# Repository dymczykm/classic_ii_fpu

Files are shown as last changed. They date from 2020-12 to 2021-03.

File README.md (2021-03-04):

# Macintosh Classic II FPU card

This repo contains a KiCAD design of an expansion card that adds an MC68882 FPU to your Macintosh Classic II. The board has two layers to keep the PCB cost down. It offers a switchable clock source between the system clock (16 MHz, synchronous operation) and a crystal oscillator on the board (40 MHz, asynchronous operation; tested with MC68882FN40A, the rumours claim 50 MHz will work too).

### Results

After plugging in the card, it should be immediately visible in some tools (here System Information of MacBench):
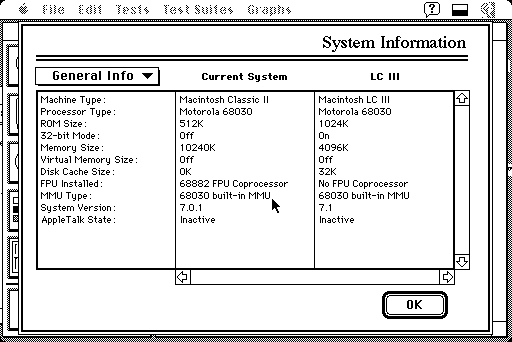
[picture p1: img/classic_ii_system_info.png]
FPU card present in System Information


The board dramatically improves the Floating Point performance of the computer. MacBench 1.0 with an FPU@16 MHz (system clock) reports over a 13x improvement.
When using an external 40 MHz oscillator, the Floating Point result goes up even a bit more - to 15.7x (it's not proportional to the clock frequency as at some point the slow 16-bit bus becomes a limiting factor):

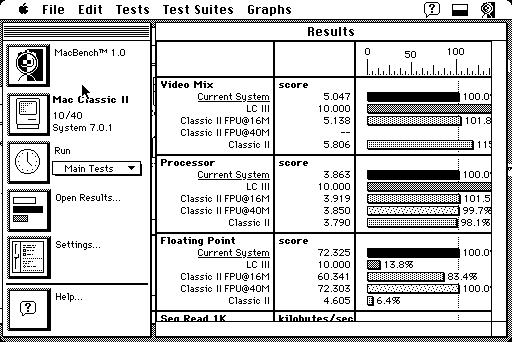
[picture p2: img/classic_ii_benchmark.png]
FPU benchmark showing Floating Point improvements


(look at the Floating Point row)

### Order a PCB

If you want to order a PCB directly, I have created a project on PCBWay:
https://www.pcbway.com/project/shareproject/Macintosh_Classic_II_FPU_card.html

### Bill of Materials

| Qty | Value | Device | Package | Parts | Digikey reference | 
|-----|---|---|---|---|---|
| 1 | | MC68882FN40A | PLCC68 | IC1 | | 
| 1 | | PLCC68 socket | PLCC68 | hosts IC1 | 2057-PLCC-68-AT-ND | 
| 1 | | TE 5-532955-8 | | J2 | A34313-ND | 
| 1 | | Pin Header 2.54mm  | 3 pins | J1 | |
| 6 | 100nF X7R | SMD capacitor | 0805 | C1-C5, C7 | 399-17169-6-ND | 
| 1 | 10uF 10V | Tantalum Cap | A (3216) | C6 | 399-4788-1-ND | 
| 1 | 51 ohm | SMD resistor | 0805 | R1 | A126374CT-ND | 
| 1 | 40 MHz | Crystal oscillator | DIP-8 | X1 | e.g. MXO45HS-2C-40M000000 | 
| 1 | | Shunt jumper | | over J1 | 881545-1 | 

(sorry, I had most components at hand, so I only have Digikey references for the rather specific ones)

### Pictures

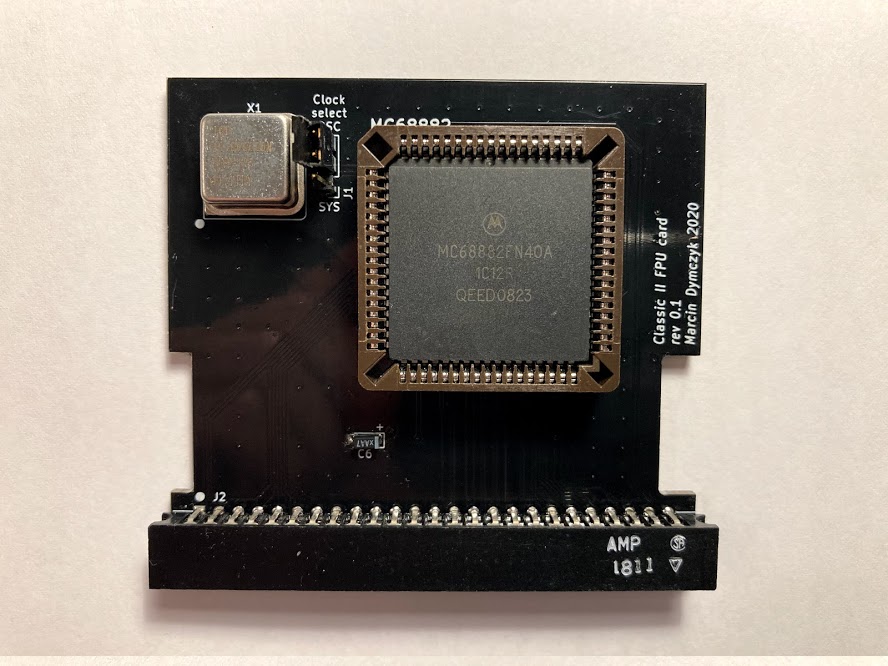
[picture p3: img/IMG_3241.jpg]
FPU top


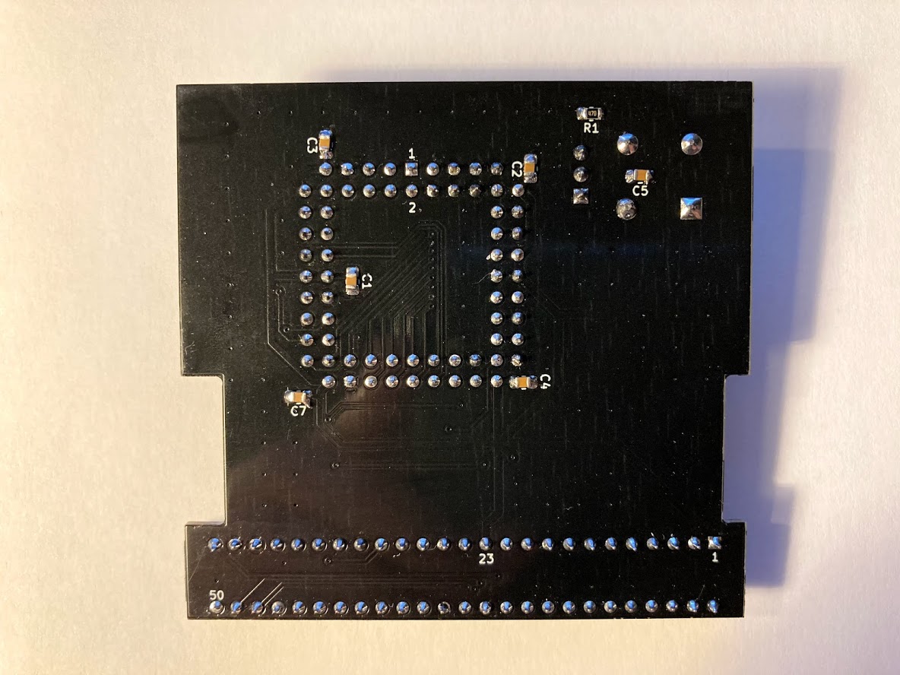
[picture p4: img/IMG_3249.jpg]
FPU bottom


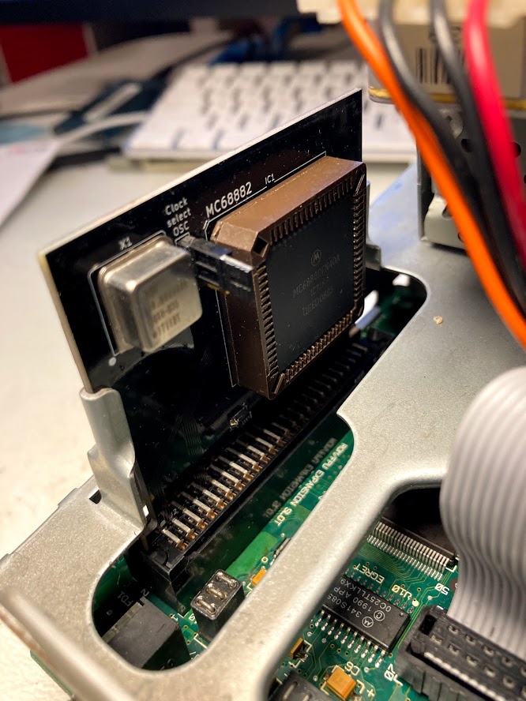
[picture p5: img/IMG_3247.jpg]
FPU installed


### References and Credits

The MC68000 KiCAD library from https://dev.sigpipe.me/DashieElectronics/Jackalope

Thanks to [pfuentes69](https://github.com/pfuentes69) for providing the missing Digikey PNs.

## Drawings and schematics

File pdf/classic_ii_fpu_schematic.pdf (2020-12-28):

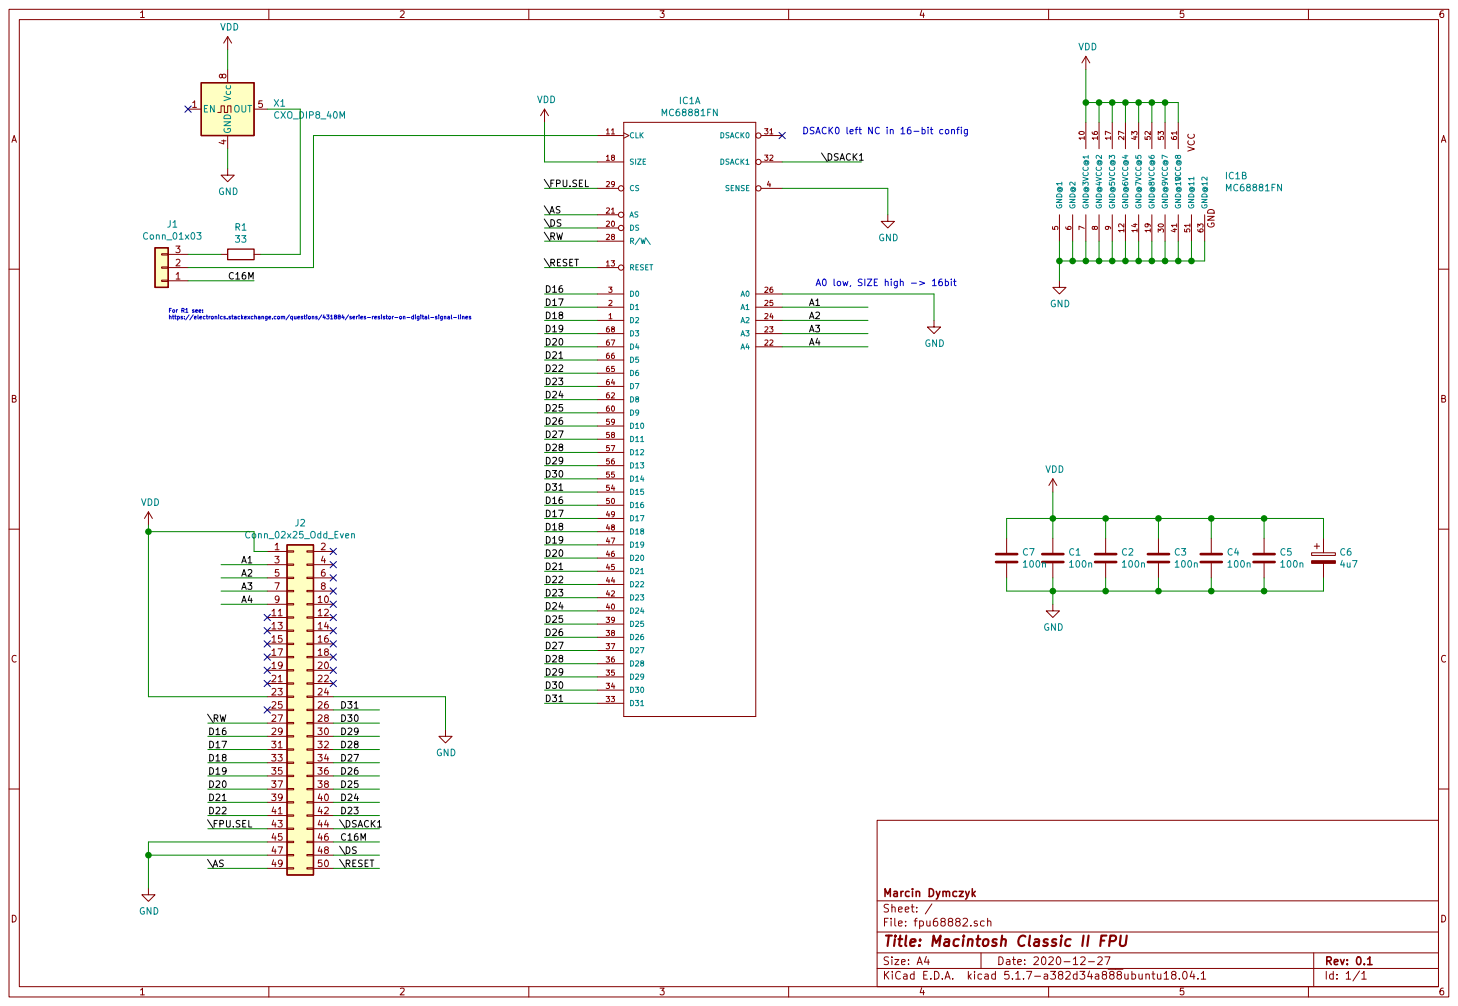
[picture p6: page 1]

DSACK0 left NC in 16-bit config

Id: 1/1 Title: Macintosh Classic II FPU

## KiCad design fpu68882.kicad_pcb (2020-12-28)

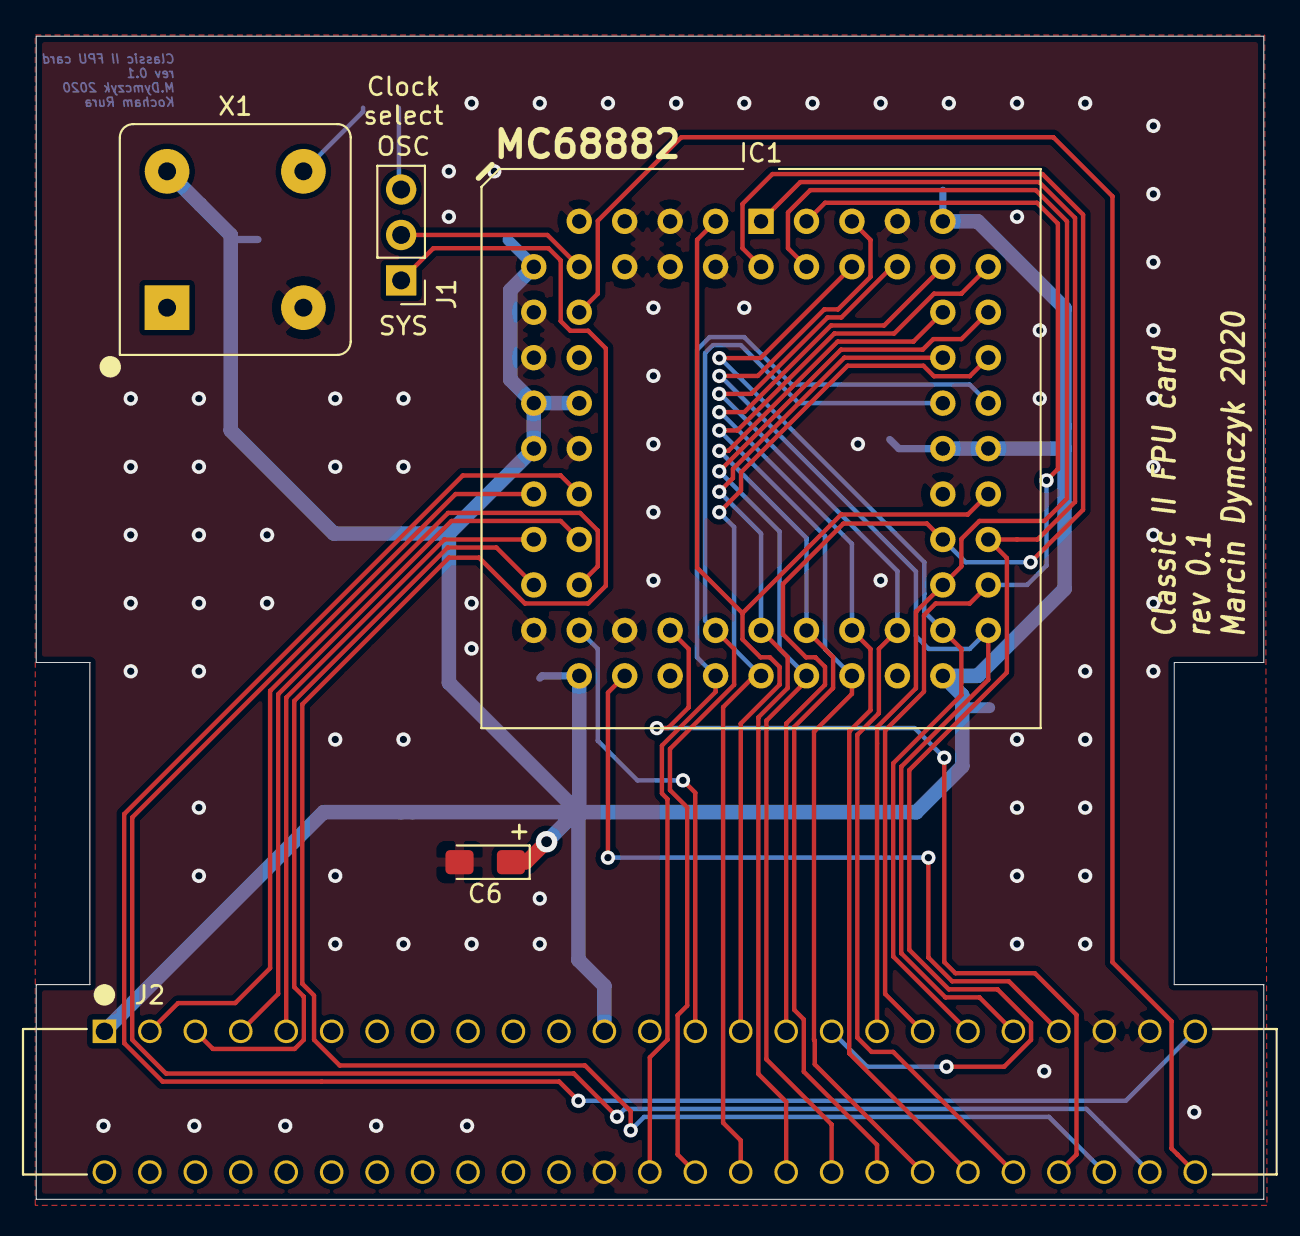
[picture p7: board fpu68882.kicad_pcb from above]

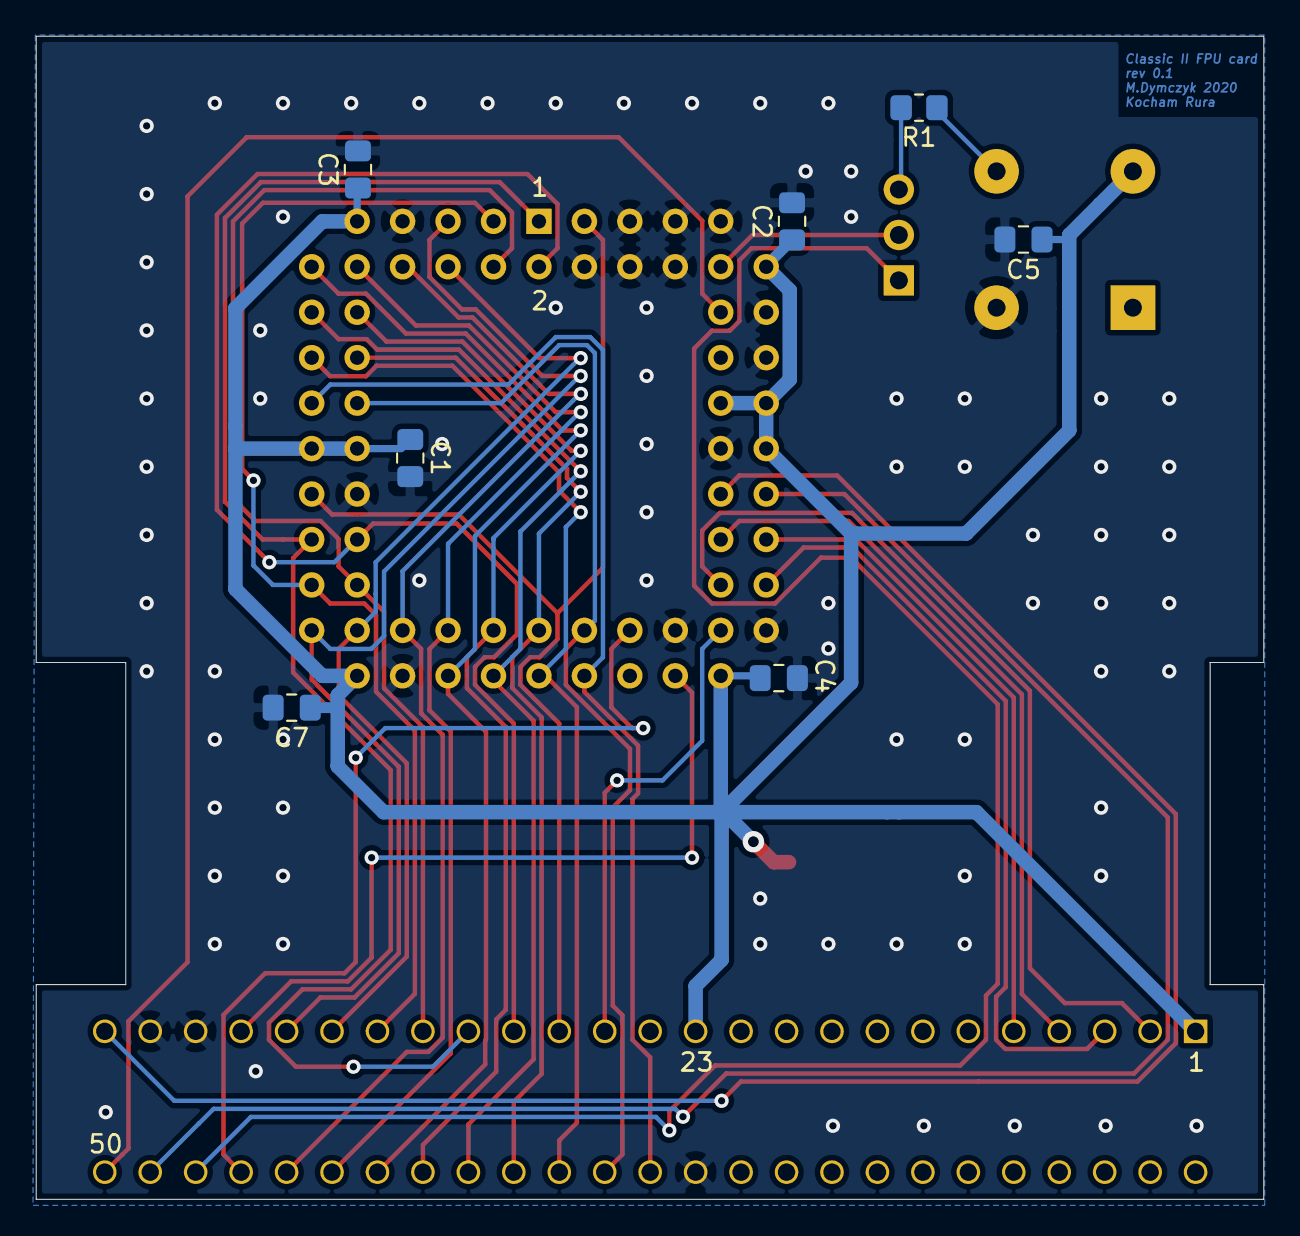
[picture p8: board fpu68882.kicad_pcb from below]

Board: 2 copper layers, 68.6 x 65.0 mm, 12 parts (7 on the bottom side), 32 nets.

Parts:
C1, C2, C3, C4, C5, C7: 100n; C_0805_2012Metric_Pad1.18x1.45mm_HandSolder
C6: 4u7; CP_EIA-3216-18_Kemet-A_Pad1.58x1.35mm_HandSolder
IC1: MC68881FN; PLCC-68_THT-Socket
J1: Conn_01x03; PinHeader_1x03_P2.54mm_Vertical
J2: Conn_02x25_Odd_Even; TE_5-532955-8_Odd_Even
R1: 33; R_0805_2012Metric_Pad1.20x1.40mm_HandSolder
X1: CXO_DIP8_40M; Oscillator_DIP-8_LargePads

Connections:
/A1: IC1.25, J2.3
/A2: IC1.24, J2.5
/A3: IC1.23, J2.7
/A4: IC1.22, J2.9
/C16M: J1.1, J2.46
/D16: IC1.3, IC1.50, J2.29
/D17: IC1.2, IC1.49, J2.31
/D18: IC1.1, IC1.48, J2.33
/D19: IC1.47, IC1.68, J2.35
/D20: IC1.46, IC1.67, J2.37
/D21: IC1.45, IC1.66, J2.39
/D22: IC1.44, IC1.65, J2.41
/D23: IC1.42, IC1.64, J2.42
/D24: IC1.40, IC1.62, J2.40
/D25: IC1.39, IC1.60, J2.38
/D26: IC1.38, IC1.59, J2.36
/D27: IC1.37, IC1.58, J2.34
/D28: IC1.36, IC1.57, J2.32
/D29: IC1.35, IC1.56, J2.30
/D30: IC1.34, IC1.55, J2.28
/D31: IC1.33, IC1.54, J2.26
/\AS: IC1.21, J2.49
/\DS: IC1.20, J2.48
/\DSACK1: IC1.32, J2.44
/\FPU.SEL: IC1.29, J2.43
/\RESET: IC1.13, J2.50
/\RW: IC1.28, J2.27
GND: C1.2, C2.2, C3.2, C4.2, C5.2, C6.2, C7.2, IC1.4, IC1.5, IC1.6, IC1.7, IC1.8, IC1.9, IC1.12, IC1.14, IC1.19, IC1.26, IC1.30, IC1.41, IC1.51, IC1.63, J2.24, J2.45, J2.47, X1.4
unnamed: IC1.11, J1.2
unnamed: J1.3, R1.2
unnamed: R1.1, X1.5
VDD: C1.1, C2.1, C3.1, C4.1, C5.1, C6.1, C7.1, IC1.10, IC1.16, IC1.17, IC1.18, IC1.27, IC1.43, IC1.52, IC1.53, IC1.61, J2.1, J2.23, X1.8

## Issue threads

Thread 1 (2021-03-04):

C7 Missing in BOM

pfuentes69, 2021-03-04:
Hello,
just to confirm that C7 is not in your BOM and that it's like the C1-C5 ones (10uF 10V), right?

dymczykm, 2021-03-04:
@pfuentes69
Oops, sorry, that's my fault. C7 should be indeed exactly like C1-C5 (but you are not correct with the value, it should be 100nF or a similar value). You can safely run the board without this capacitor, it should be fine too. I will correct the readme in a second.

Hope that helps!

pfuentes69, 2021-03-04:
OK. I received today the boards from PCBWAY and I was about to make one... but I didn't order C7 as I wasn't aware of it
is it better not to put any cap or to put one like C1-C5 ?
txs!

Closed 2021-03-04.

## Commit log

2020-12-28 First revision
    [fpu68882.kicad_pcb, fpu68882.sch]
2020-12-28 Commit real files, fix the relative library path.
    [fpu68882.kicad_pcb, fpu68882.sch]
2021-01-27 Add a BOM and a better description to README, no images yet.
2021-03-04 Added C7 to the BoM, thanks @pfuentes69.
